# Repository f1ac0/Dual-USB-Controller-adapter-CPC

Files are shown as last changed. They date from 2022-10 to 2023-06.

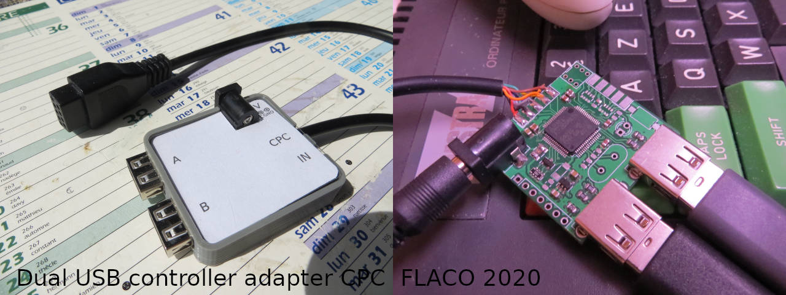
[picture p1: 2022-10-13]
Dual USB controller adapter CPC FLACO 2020.JPG

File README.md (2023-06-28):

# Dual USB Controller adapter CPC
This project is a version of the Dual USB Controller adapter project dedicated to the Amstrad CPC.
It is an interface board to connect two USB controllers on the DB9 joystick port of the Amstrad CPC.

Working so far :
- two USB ports for two USB HID devices like mouse, keyboard or joystick/gamepad
- DB9 output plug to the joystick port of the CPC
- DB9 input to daisy chain an Atari controller (with power)
- Need external 5V 0.5A supply, WITH SAME GND AS THE CPC
- gamepad compatibility
  - Tested with wired Xbox 360, PS3 and HID gamepad support and HID joystick/gamepad.
  - 3 buttons (button B is both on B and X, button 3 is on Y).
  - Autofire on right trigger
  - Auto-Left-Right on left trigger, for "sports" games :P
  - platform mode with jump mapped on a button
- mouse support with AMX compatibility
- keyboard support
  - single USB keyboard to replace two gamepads, but you can also use two keyboards
  
Limitations :
- other HID gamepads/joysticks should also work but button placement is device dependant.
- composite devices that report multiple interfaces (eg mouse and keyboard) work only with the first interface/device.

# Disclaimer
This is a hobbyist project, it comes with no warranty and no support. Also remember that the machines are about 30 years old and may fail because of such hardware expansions.

I publish my work under the CC-BY-NC-SA license. The content of this repository is the result of weeks of work, requiring investment in tools, parts, prototypes, and risky tests on his own equipment. For this reason the author does not want third parties to sell products and keep all the profit, usually without even offering support to their customers. If you see people selling this without the consent of the author, don't buy from them.

If you find it useful and want to reward me : I am always looking for Amiga/Amstrad CPC hardware to repair and hack, please contact me.

# Power, ESD and other Warning
The adapter requires an external 5V supply WITH THE SAME GROUND AS THE CPC. For this reason I recommend using the same 5V power supply as the CPC, with a Y cable.

You must not use this adapter on other host systems than the CPC or plus line : on the Amstrad CPC the second button is connected on pin 7 which is 5V on Amiga/Atari port, and pin 9 is the secondary return pin instead of the second button. This system also has two "common" pins that are not connected to ground !

The adapter's software itself supports hot-plug both on DB9 and USB port, however there is no hardware protection. The manuals of the host systems warned to always turn it off before un/plugging any device. Again, you do it at your own risk.

# BOM
- 1x STM32F205RBT6
- 1x 3.3v LDO, either SPX3819M5-L-3-3 or XC6206P332MR
- 2x 1uF (or more) 0805 capacitors
- 1x 250mA polyfuse
- 2x 2.2uF 0805 capacitors
- 5x 100nF 0805 capacitors
- 4x 22ohm 0805 resistors
- 1x 4.7K 0805 resistor
- 1x 4.7ohm 0805 resistor
- 3x 10K 0603x4 resistors array
- 2x USB A Female Socket, type G54
- 1x DB9 female sockets, 1x DB9 male socket **
- 1x barrel jack connector, 5.5x2.5 or 5.5x2.1 depending on your PSU (the first one is used on plus systems and the second one on classic CPC)
- D1 led and R3, D2 and R4 are optional
- The SW1 switch, SW2 button, Y1 crystal and C1, C2 capacitors, RN1, D3 are not used

Power and programming headers are optional : just maintain the connection during the 5 seconds of the programming operation. It will also be easier to put the device in an enclosure without it.

** I recommend using the connectors from a "Genesis gamepad extension cord" instead to avoid metallic shielding that can make shorts when connecting live. Otherwise you can solder standard plugs with the PCB board sandwiched between the pins.

# Making it
Components are SMD, and have thin pin pitch. You need to know what you are doing. Check for shorts at least between 5V, 3.3V, and GND traces before applying power !

Since 06-2023 the firmware is made of two parts to ease future application update by users :
- A bootloader, that must be flashed at address $08000000 in the MCU using dedicated tools such as stlink with the open-source tools (https://github.com/stlink-org/stlink) or STM32CubeProgrammer, or TTL serial adapter with stm32flash.
- The application, that is flashed by the bootloader and can be updated later on : place the .upd file at the root of a FAT USB mass storage device, plug the mass storage in port A, and power up the adapter for at least 10s or until the LED of the USB key stops flashing.

The bootloader and application firmware are compiled using STM32CubeIDE.

# Using it
- Plug the DB9 cable
- Plug the USB controllers
- Plug the 5V barrel jack
- Switch power and CPC on

To keep things simple to use, each port has a preferred USB input : Joystick 1 with USB A and 2 with USB B. Except the mouse that must be connected on port B.
Here is more information about the USB devices you can connect.

## USB Mouse
Supports USB1 or USB2 mouse, and emulates an AMX mouse.
Mouse must be connected on USB B and movements are sent on port 1.

## USB Keyboard
Supports USB keyboard in boot mode, and emulates at the same time two controllers on both ports.
Joystick 1 : AQOP or AQRT + Space or left Alt + Enter or Y
Joystick 2 : Keypad 7456 + 0 or 1 + Enter or '+'
The layouts are exchanged when plugged in the USB B port.

## XBOX360 and PS3 gamepad
Supports wired USB original and clones, and emulates a joystick, mouse, or dual pads depending on the active mode.

The round button and leds are used as a mode selector : press the round button to change mode.
5 modes are implemented by default, a few others are available in the source code, and you can make your own since it is open source :).

1. gamepad + mouse on preferred port : default
  * Preferred port = Game : left stick and cross, autofire on right trigger
  * Preferred port = Mouse : right stick, left button is right stick hat and right button is back, autofire on left trigger

2. gamepad + mouse on other port
  * Other port = Game : left stick and cross, autofire on right trigger
  * Other port = Mouse : right stick, left button is right stick hat and right button is back, autofire on left trigger

3. dual gamepads. Are there dual stick shooters on the CPC yet ?
  * Preferred port = Game : left stick and cross, autofire on right trigger
  * Other port = Game : right stick, left button is right stick hat and right button is back, autofire on left trigger

4. mouse mode.
  * Preferred port = Mouse : left stick and cross, autofire on right trigger
  * Other port = Game : right stick, left button is right stick hat and right button is back

5. 2 players on one controller mode. To play with a friend when you are short on controllers, and are not afraid of a stiff neck.
  * Preferred port = Game : left part of the controller, 90° clockwise, autofire on left trigger
  * Other port = Game : right part of the controller, 90° counterclockwise, autofire on right trigger

## Other gamepad
May work with standard HID gamepads and emulates joystick on left stick, and mouse on right stick.
Since they are not normalized inside the USB documentation, right stick and buttons position will vary between controllers. Some even have strange things in their report descriptor which may also break their compatibility. Others need pressing an analog/digital button on the gamepad itself.

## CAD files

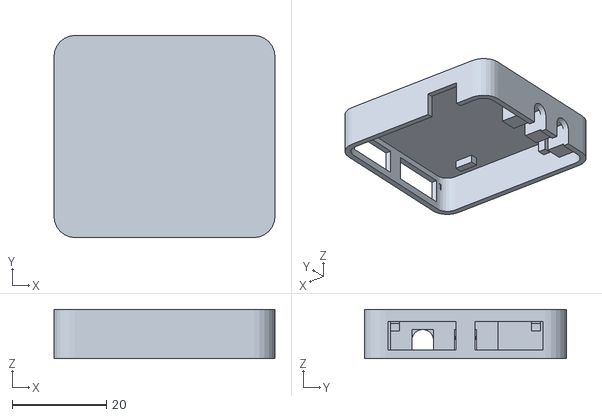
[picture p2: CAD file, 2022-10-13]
Case/case_bottom_cable.stl
47.0 x 43.0 x 10.5

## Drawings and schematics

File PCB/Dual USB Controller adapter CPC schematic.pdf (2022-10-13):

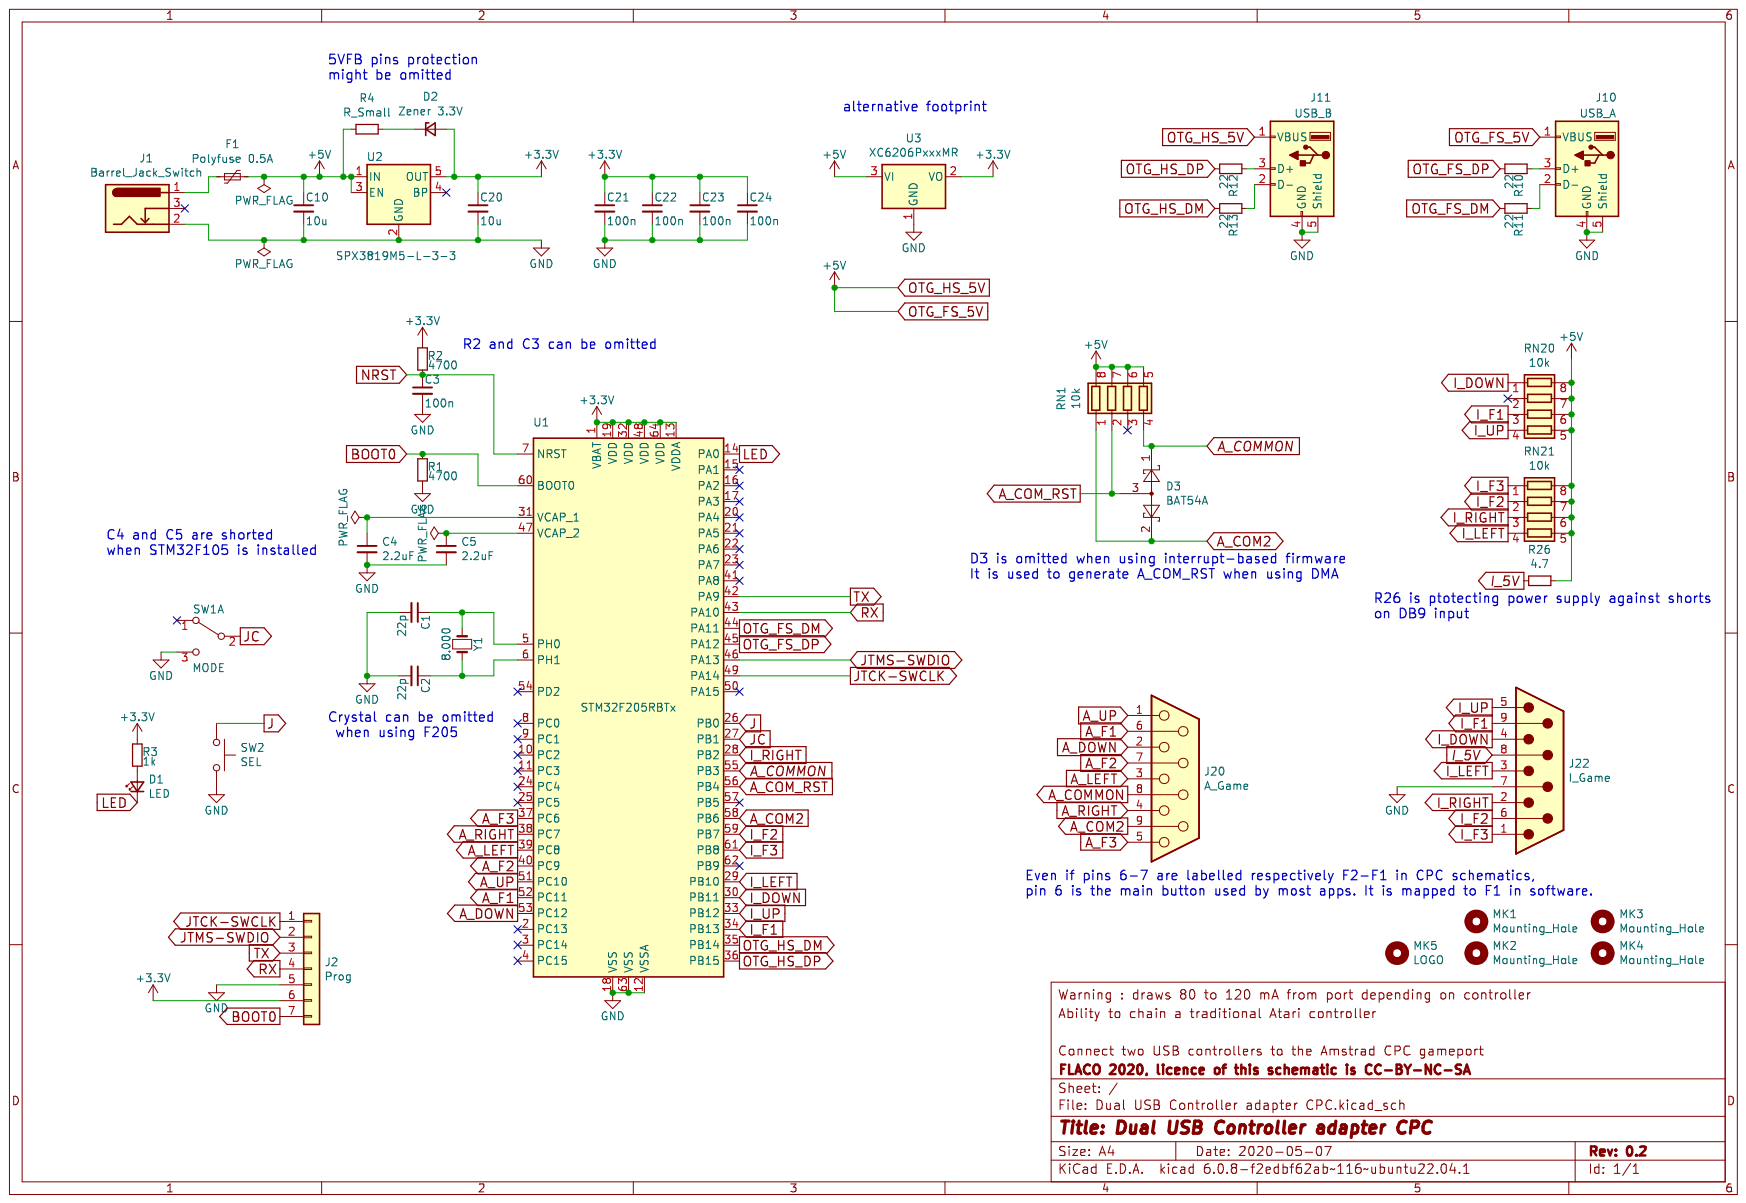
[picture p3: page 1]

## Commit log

2022-10-13 Public repository init with schematic, Gerbers, ibom, STM32 bin, case files, Photo, Readme, License
    [Dual USB Controller adapter CPC-B_Cu.gbl, Dual USB Controller adapter CPC-B_Mask.gbs, Dual USB Controller adapter CPC-B_Paste.gbp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]
2023-06-12 STM32: new firmware with PS3 controller support and improved HID report descriptor parsing.
2023-06-28 STM32 : Addition of a bootloader to ease the firmware update with a USB mass storage device
2024-01-15 STM32: fix hat switch up+left was reported as down+left.
